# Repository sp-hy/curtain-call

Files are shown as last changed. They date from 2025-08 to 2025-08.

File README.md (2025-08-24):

# CurtainCall - Smart Curtain Controller v2.0

A precision smart curtain controller featuring Zigbee connectivity and magnetic position sensing for accurate, reliable curtain automation.

## Features

- **Precision Position Tracking**: AS5600 magnetic rotation sensor with 0.0879° resolution
- **Zigbee 3.0 Integration**: Full home automation compatibility with window covering cluster
- **Robust Motor Control**: BTS7960 high-current motor driver for smooth, powerful operation
- **Real-time Position Feedback**: Continuous monitoring with 20ms update intervals
- **Advanced Error Handling**: I2C recovery, spike detection, and safety limits
- **Multi-rotation Support**: Handles up to 5 full rotations (1800°) for long curtain runs
- **Auto-calibration**: Intelligent position recovery on power-up

## Bill of Materials (BOM)

### Core Components
| Component | Quantity | Description | Estimated Cost |
|---|---|---|---|
| ESP32 DevKit | 1 | Main microcontroller with Zigbee 3.0 support | $8-12 |
| AS5600 Magnetic Encoder | 1 | 12-bit contactless position sensor | $3-5 |
| BTS7960 Motor Driver | 1 | 43A high-power motor controller | $8-12 |
| 12V DC Geared Motor | 1 | High-torque motor for curtain operation | $15-25 |
| Diametric Magnet | 1 | 6mm diameter for AS5600 sensor | $2-3 |

### Power & Protection
| Component | Quantity | Description | Estimated Cost |
|---|---|---|---|
| 12V 3A Power Supply | 1 | Wall adapter or switching supply | $10-15 |
| LM2596 Buck Converter | 1 | 12V to 5V step-down (optional) | $3-5 |
| Fuse Holder & 5A Fuse | 1 | Motor circuit protection | $2-3 |
| TVS Diode (15V) | 2 | Motor voltage spike protection | $1-2 |

### Mechanical Hardware
| Component | Quantity | Description | Estimated Cost |
|---|---|---|---|
| Motor Mounting Bracket | 1 | Custom or universal motor mount | $5-10 |
| Drive Pulley/Gear | 1 | Connects motor to curtain mechanism | $3-8 |
| Timing Belt/Chain | 1 | Power transmission (if required) | $5-10 |
| Shaft Coupling | 1 | Flexible coupling for sensor mounting | $3-5 |

### Electronics & Wiring
| Component | Quantity | Description | Estimated Cost |
|---|---|---|---|
| Dupont Jumper Wires | 20 | Male-female and male-male connectors | $3-5 |
| Breadboard/PCB | 1 | Prototyping or permanent mounting | $2-8 |
| Terminal Blocks | 4 | Power and motor connections | $2-4 |
| Heat Shrink Tubing | 1 set | Wire protection and insulation | $3-5 |

**Total Estimated Cost: $75-140** (depending on motor choice and sourcing)

## Wiring Diagrams

### Circuit Schematic

```
                     CurtainCall v2.0 Circuit Diagram
    
    12V PSU ───[FUSE]───┬─── BTS7960 VCC ───┬─── M+ ───┐
        │               │                   │          │
        └─── Buck Conv ─┘                   │          │    ┌─── DC MOTOR ───┐
                 │                          │          │    │               │
                5V                          │        [TVS]  │               │
                                            │          │    │               │
    ┌─────────────── ESP32 DevKit ──────────┼──────────┼────┼───────────────┼───┐
    │                                       │          │    │               │   │
    │  GPIO 21 (SDA) ─────────────────────┐ │          │    │               │   │
    │  GPIO 22 (SCL) ─────────────────────┼─┼──────────┼────┼───────────────┼───┼─ GND
    │  GPIO  0 ───── BTS7960 L_EN         │ │          │    │               │   │
    │  GPIO  7 ───── BTS7960 R_EN         │ │          └──M-┘               │   │
    │  GPIO  6 ───── BTS7960 L_PWM        │ │                               │   │
    │  GPIO  5 ───── BTS7960 R_PWM        │ │                               │   │
    │                                     │ │         ┌─── AS5600 ──────────┐   │
    │  3.3V ──────────────────────────────┼─┼─────────┼─ VCC               │   │
    │  GND ───────────────────────────────┼─┼─────────┼─ GND               │   │
    └─────────────────────────────────────┼─┼─────────┼─────────────────────┼───┘
                                          │ │         │                     │
                                          │ └─────────┼─ SDA               │
                                          └───────────┼─ SCL               │
                                                      │                     │
                                              ┌───────┼─ MAGNET ────────────┘
                                              │       └─────────────────────┐
                                              │                             │
                                        Rotating Shaft/Pulley              │
                                              │                             │
                                              └─────── Curtain Rod ─────────┘

    Components:
    - ESP32: Main controller with Zigbee
    - AS5600: Magnetic rotation encoder  
    - BTS7960: High-current motor driver
    - TVS: Transient voltage suppressor
    - Buck Conv: 12V to 5V converter (optional)
```

### Power Distribution

```
12V Power Supply (3A)
│
├── 5A Fuse ──► BTS7960 Motor Driver (12V)
│                    │
│                    └── DC Motor (12V)
│
└── LM2596 Buck Converter (Optional)
         │
         └── 5V for BTS7960 logic (if needed)

ESP32 provides 3.3V for AS5600 sensor
```

### Pin Assignment Table

| ESP32 Pin | Function | Connected To | Signal Type |
|---|---|---|---|
| GPIO 21 | I2C SDA | AS5600 SDA | Digital I2C |
| GPIO 22 | I2C SCL | AS5600 SCL | Digital I2C |
| GPIO 0 | Motor Control | BTS7960 L_EN | Digital Output |
| GPIO 7 | Motor Control | BTS7960 R_EN | Digital Output |
| GPIO 6 | Motor PWM | BTS7960 L_PWM | PWM Output |
| GPIO 5 | Motor PWM | BTS7960 R_PWM | PWM Output |
| 3.3V | Power | AS5600 VCC | Power Supply |
| GND | Ground | All GND pins | Common Ground |

## AS5600 Magnetic Encoder Setup

The AS5600 provides precise angular position measurement with contactless operation:

### Physical Installation
1. **Mount the sensor** securely to a stationary part of the curtain mechanism
2. **Attach the magnet** to the rotating element (motor shaft, pulley, or gear)
3. **Maintain 1-3mm air gap** between magnet and sensor for optimal performance
4. **Center alignment** is critical - magnet must be concentric with sensor
5. **Use diametric magnetization** for best linearity and accuracy

### Technical Specifications
- **I2C Address**: 0x36 (factory default, programmable)
- **Resolution**: 12-bit (4096 steps = 0.0879° per step)
- **Angular Range**: Full 360° rotation
- **Magnetic Field**: 30-100 mT optimal range
- **Update Rate**: 20ms intervals (50Hz) for I2C stability
- **Supply Voltage**: 3.3V from ESP32
- **Current Consumption**: 6.5mA typical

## Software Installation

### Required Libraries
1. **AS5600 Library**: `#include <AS5600.h>`
   - [AS5600 Library](https://github.com/RobTillaart/AS5600) by Rob Tillaart
2. **BTS7960 Motor Driver**: `#include <BTS7960.h>`
   - Available through Arduino Library Manager
3. **Zigbee Core**: Built into ESP32 Arduino Core v3.0+
   - `#include "ZigbeeCore.h"`
   - `#include "ep/ZigbeeWindowCovering.h"`

### Installation Steps
1. **Install ESP32 Arduino Core** (v3.0 or later for Zigbee support)
2. **Install required libraries** through Arduino IDE Library Manager
3. **Upload CurtainCall.ino** to your ESP32
4. **Configure your home automation** to recognize the new Zigbee device

### Configuration Parameters
```cpp
// Hardware configuration (CurtainCall.ino lines 24-38)
const int MOTOR_SPEED = 200;                    // PWM value (0-255)
const float TOTAL_ROTATIONS_0_TO_100 = 5.0;    // Total rotations for full travel
const float MAX_ANGLE_CHANGE_PER_MS = 15.0;    // Spike detection threshold
const unsigned long AS5600_READ_INTERVAL = 20;  // Sensor read interval (ms)
```

## Usage

### Basic Operation
The system tracks curtain position through absolute angle measurement:

- **0%**: Fully closed (0° absolute angle)
- **100%**: Fully open (1800° absolute angle = 5 full rotations)
- **Real-time tracking**: 20ms update intervals with spike detection
- **Multi-rotation support**: Handles up to 5 complete rotations
- **Auto-calibration**: Intelligent position recovery on startup

### Zigbee Integration
The device appears as a **Window Covering** in your Zigbee network with these commands:

| Zigbee Command | Function | Description |
|---|---|---|
| `Open` | `openCurtain()` | Move to 100% open position |
| `Close` | `closeCurtain()` | Move to 0% closed position |
| `GoToLiftPercentage` | `moveToPosition(uint8_t)` | Move to specific percentage |
| `Stop` | `stopCurtain()` | Immediately stop movement |

### System Features
- **Precise Position Control**: 0.0879° resolution with AS5600 encoder
- **Safety Limits**: Automatic stop at 0% and 100% positions  
- **Error Recovery**: I2C communication recovery and spike filtering
- **Smooth Movement**: BTS7960 provides smooth acceleration/deceleration
- **Status Reporting**: Real-time position updates to Zigbee coordinator

### Initial Setup
1. **Power on** the device - it will join your Zigbee network automatically
2. **Manual positioning** - move curtain to known position (e.g., 50% open)
3. **Auto-calibration** - system calculates absolute position based on stored state
4. **Test operation** - use home automation to verify full range movement

## Configuration

### Pin Definitions
```cpp
#define AS5600_SDA 21  // I2C SDA pin
#define AS5600_SCL 22  // I2C SCL pin
#define MOTOR_L_EN 0   // Motor enable left
#define MOTOR_R_EN 7   // Motor enable right
#define MOTOR_L_PWM 6  // Motor PWM left
#define MOTOR_R_PWM 5  // Motor PWM right
```

### Motor Settings
```cpp
const int MOTOR_SPEED = 200;        // PWM value (0-255)
const int UPDATE_INTERVAL_MS = 100; // Position update frequency
```

## Troubleshooting

### Power Issues
- **Device not starting**: Check 12V power supply capacity (minimum 2A)
- **Random resets**: Verify all ground connections are secure
- **Motor stops unexpectedly**: Check fuse, may need higher current rating

### AS5600 Sensor Issues
- **Position not updating**: Check I2C wiring (SDA/SCL crossed or loose)
- **Erratic readings**: Verify magnet alignment (must be centered over sensor)
- **Sensor timeouts**: System includes automatic I2C recovery after 5 failures
- **Wrong direction**: Adjust `MOTOR_DIRECTION_INVERTED` in code

### Motor Control Issues  
- **Motor not responding**: Verify BTS7960 enable pins and PWM connections
- **Wrong rotation direction**: Check motor wires or toggle direction setting
- **Jerky movement**: Reduce `MOTOR_SPEED` value or check mechanical binding
- **Overshooting target**: Adjust `DEGREES_PER_PERCENT` for your curtain travel

### Zigbee Connectivity
- **Device not joining network**: Ensure ESP32 Arduino Core v3.0+ is installed
- **Commands not working**: Check if device appears as "Window Covering" type
- **Position not updating**: Verify Zigbee coordinator supports position feedback

### Position Tracking
- **Incorrect position after power-up**: System auto-calibrates based on last known position
- **Drift over time**: Check for mechanical backlash in drive system
- **Sudden position jumps**: Spike detection active - check magnet mounting
- **Limited range**: Adjust `TOTAL_ROTATIONS_0_TO_100` for your curtain system

## Advanced Features

### Custom Rotation Range
Modify the rotation range for different curtain mechanisms:

```cpp
curtain.totalRotation = 180.0; // For 180-degree rotation
```

### Direction Configuration
Change sensor direction if needed:

```cpp
as5600.setDirection(AS5600_COUNTERCLOCK_WISE);
```

### Error Handling
The system includes error checking for:
- Sensor communication failures
- Invalid position values
- Motor control issues

## License

This project is open source. Please refer to the individual library licenses for the AS5600 and other dependencies.

## Contributing

Contributions are welcome! Please feel free to submit pull requests or open issues for bugs and feature requests.

## Acknowledgments

- [Rob Tillaart](https://github.com/RobTillaart) for the excellent AS5600 library
- The open source community for Zigbee and motor control libraries

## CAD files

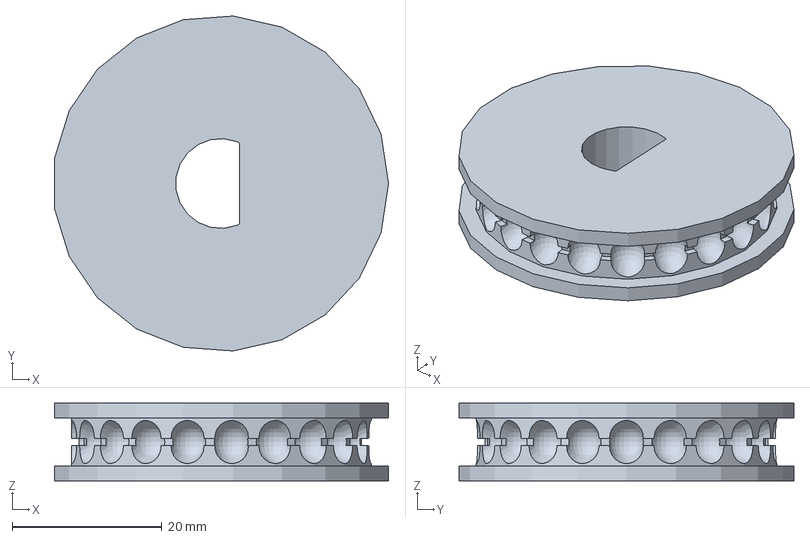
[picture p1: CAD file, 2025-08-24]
3D parts/gear/bead_chain_gear-12mm.3mf
44.6 x 44.7 x 10.4 mm

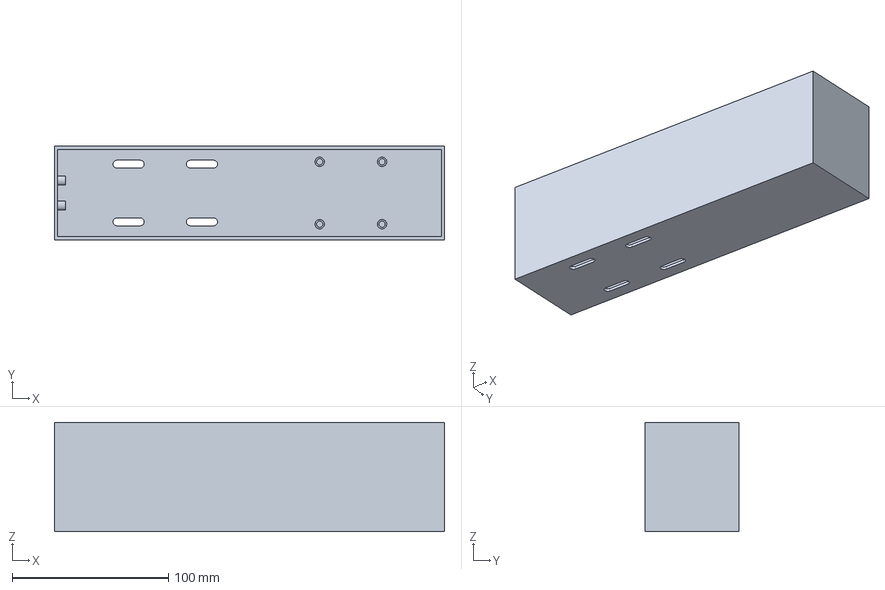
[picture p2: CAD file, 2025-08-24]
3D parts/housing/housing.FCStd
250.0 x 60.0 x 70.0 mm

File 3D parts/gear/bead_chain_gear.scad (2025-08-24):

$fn=21;
r = 20.1275367222;
ball_radius = 4.6/2; //6.05/2; //4.45/2;
h = ball_radius * 2 * (1 + .25 + .2 );
echo(h);
n_teeth=21;
link_radius=.5;
cover_height=2;
shaft_radius = 12/2; // 12mm diameter D-shaft
d_shaft_flat_depth = 0.5; // Adjust this value to match your motor shaft's flat depth

module make_sphere_ring(ring_radius, sphere_radius, num_spheres) {
  union(){
    for (i = [0:num_spheres]){
      rotate([0,0,i*360/num_spheres])
        translate([ring_radius,0,0])hull() {
          sphere(sphere_radius);
          translate([-.5 * sphere_radius,0,0])sphere(sphere_radius);
          translate([0,0,.25 * sphere_radius])sphere(sphere_radius);
          translate([0,0,-.25 * sphere_radius])sphere(sphere_radius);
        }
    }
  }
}

module make_torus(ring_radius, inner_radius) {
  // openscad apparently can't handle rotate_extrude in a difference, so this isn't a real cylinder
  /*rotate_extrude(convexity=10)translate([ring_radius, 0, 0])circle(inner_radius);*/
  difference() {
    cylinder (
        h = inner_radius*2,
        r = ring_radius,
        center = true);
    cylinder (
        h = inner_radius * 2,
        r = ring_radius - 2*inner_radius,
        center = true);
  }
}

module bead_ring() {
  union() {
    make_sphere_ring(r, ball_radius, n_teeth);
    make_torus(r, link_radius);
  }
}

module d_shaft_hole(shaft_r, flat_depth, shaft_height) {
  difference() {
    cylinder(r=shaft_r, h=shaft_height, center=true);
    translate([shaft_r - flat_depth, 0, 0])
      cube([shaft_r, shaft_r * 2, shaft_height + 1], center=true);
  }
}

module make_gear() {
  difference() {
    union() {
      cylinder(h=h, r=r, center=true);
      translate([0,0,-.9*(h-cover_height)])
        cylinder(h=cover_height, r=r+ball_radius, center=true);
      translate([0,0,.9*(h-cover_height)])
        cylinder(h=cover_height, r=r+ball_radius, center=true);
    }
    /*cylinder(h=h, r=r, center=true);*/
    # d_shaft_hole(shaft_radius, d_shaft_flat_depth, h + 4 * cover_height);
    # bead_ring();
  }
}

make_gear();
/*bead_ring() ;*/
/*make_torus(r, link_radius);*/

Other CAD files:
3D parts/housing/housing.3mf

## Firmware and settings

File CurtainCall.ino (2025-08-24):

/*
 * CurtainCall - Smart Curtain Controller
 * 
 * Motorized curtain control system with Zigbee connectivity
 * Features precision position tracking using AS5600 magnetic encoder
 * 
 * Hardware:
 * - ESP32 microcontroller
 * - BTS7960 motor driver
 * - AS5600 magnetic rotary encoder
 * - DC motor with magnetic coupling
 * 
 * Author: CurtainCall Project
 * Version: 2.0
 */

#include <BTS7960.h>
#include "ZigbeeCore.h"
#include "ep/ZigbeeWindowCovering.h"
#include <AS5600.h>
#include <Wire.h>

// Hardware pin assignments
#define ZIGBEE_ENDPOINT 10
#define MOTOR_L_EN 0
#define MOTOR_R_EN 7
#define MOTOR_L_PWM 6
#define MOTOR_R_PWM 5
#define SDA_PIN 21
#define SCL_PIN 22

// System configuration
const int MOTOR_SPEED = 200;
const bool MOTOR_DIRECTION_INVERTED = true;
const unsigned long AS5600_READ_INTERVAL = 20;  // 20ms for I2C stability
const float TOTAL_ROTATIONS_0_TO_100 = 5.0;    // Configure for your curtain travel
const float DEGREES_PER_PERCENT = TOTAL_ROTATIONS_0_TO_100 * 360.0 / 100.0;
const float MAX_ANGLE_CHANGE_PER_MS = 15.0;    // Spike detection threshold

// Hardware interfaces
BTS7960 motor(MOTOR_L_EN, MOTOR_R_EN, MOTOR_L_PWM, MOTOR_R_PWM);
AS5600 as5600;
ZigbeeWindowCovering zigbeeEndpoint(ZIGBEE_ENDPOINT);

// System state
struct {
  uint8_t current = 100;      // Current position (0-100%)
  uint8_t target = 100;       // Target position (0-100%)
  bool isMoving = false;      // Movement state
  int direction = 0;          // 1=opening, -1=closing, 0=stopped
  float absoluteAngle = 0.0;  // Absolute angle from 0% position
  bool calibrated = false;    // Calibration status
} curtain;

// Encoder state
struct {
  float lastAngle = 0.0;
  float currentAngle = 0.0;
  float validAngle = 0.0;     // Last validated reading
  int rotationCount = 0;      // Track multiple rotations
  bool initialized = false;
  unsigned long lastReadTime = 0;
} encoder;

void setup() {
  // Initialize hardware
  initializeMotor();
  initializeEncoder();
  initializeZigbee();
  
  // Set initial position
  zigbeeEndpoint.setLiftPercentage(curtain.current);
}

void loop() {
  // Update encoder reading
  if (millis() - encoder.lastReadTime >= AS5600_READ_INTERVAL) {
    updateEncoder();
  }
  
  // Update position and motor control
  updatePosition();
}

void initializeMotor() {
  motor.begin();
  motor.enable();
  motor.stop();
}

void initializeEncoder() {
  // Configure I2C for reliability
  Wire.begin(SDA_PIN, SCL_PIN);
  Wire.setClock(100000);  // 100kHz for stability
  Wire.setTimeout(1000);
  
  // Initialize AS5600
  as5600.begin();
  
  if (!as5600.isConnected()) {
    return;  // Continue without encoder if not available
  }
  
  // Read initial position
  uint16_t rawAngle = as5600.readAngle();
  encoder.currentAngle = rawAngle * AS5600_RAW_TO_DEGREES;
  encoder.lastAngle = encoder.currentAngle;
  encoder.validAngle = encoder.currentAngle;
  encoder.rotationCount = 0;
  encoder.initialized = true;
  
  // Auto-calibrate based on stored position
  float targetAbsoluteAngle = curtain.current * DEGREES_PER_PERCENT;
  encoder.rotationCount = round((targetAbsoluteAngle - encoder.currentAngle) / 360.0);
  curtain.absoluteAngle = encoder.rotationCount * 360.0 + encoder.validAngle;
  curtain.calibrated = true;
}

void initializeZigbee() {
  // Configure device properties
  zigbeeEndpoint.setManufacturerAndModel("LC", "CurtainCall2");
  zigbeeEndpoint.setCoveringType(DRAPERY);
  zigbeeEndpoint.setConfigStatus(true, true, false, true, true, true, true);
  zigbeeEndpoint.setMode(false, true, false, false);
  zigbeeEndpoint.setLimits(0, 200, 0, 0);
  
  // Register command callbacks
  zigbeeEndpoint.onOpen(openCurtain);
  zigbeeEndpoint.onClose(closeCurtain);
  zigbeeEndpoint.onGoToLiftPercentage(moveToPosition);
  zigbeeEndpoint.onStop(stopCurtain);
  
  Zigbee.addEndpoint(&zigbeeEndpoint);
  
  // Connect to network
  if (!Zigbee.begin()) {
    ESP.restart();  // Restart if Zigbee fails
  }
  
  while (!Zigbee.connected()) {
    delay(100);
  }
}

void updateEncoder() {
  if (!as5600.isConnected() || !encoder.initialized) {
    return;
  }
  
  // Read with retry logic for reliability
  uint16_t rawAngle = 0;
  bool readSuccess = false;
  
  for (int attempt = 0; attempt < 3 && !readSuccess; attempt++) {
    if (attempt > 0) delay(5);
    
    unsigned long startTime = micros();
    if (as5600.isConnected()) {
      rawAngle = as5600.readAngle();
      if ((micros() - startTime) < 20000) {  // Valid if < 20ms
        readSuccess = true;
      }
    }
  }
  
  // Handle failed reads gracefully
  if (!readSuccess) {
    static unsigned long consecutiveErrors = 0;
    consecutiveErrors++;
    
    // Attempt I2C recovery after multiple failures
    if (consecutiveErrors >= 5) {
      Wire.end();
      delay(50);
      Wire.begin(SDA_PIN, SCL_PIN);
      Wire.setClock(100000);
      Wire.setTimeout(1000);
      delay(50);
      consecutiveErrors = 0;
    }
    
    encoder.currentAngle = encoder.validAngle;
    encoder.lastReadTime = millis();
    return;
  }
  
  encoder.currentAngle = rawAngle * AS5600_RAW_TO_DEGREES;
  
  // Spike detection and filtering
  unsigned long currentTime = millis();
  unsigned long deltaTime = max(1UL, currentTime - encoder.lastReadTime);
  
  float angleDifference = encoder.currentAngle - encoder.lastAngle;
  
  // Handle 360° rollover
  if (angleDifference > 180.0) angleDifference -= 360.0;
  else if (angleDifference < -180.0) angleDifference += 360.0;
  
  // Check for unreasonable changes (spikes)
  float maxChange = MAX_ANGLE_CHANGE_PER_MS * deltaTime;
  if (curtain.isMoving) maxChange *= 2.0;  // More lenient when moving
  
  bool isValidReading = (encoder.lastReadTime == 0) || 
                       (abs(angleDifference) <= maxChange) || 
                       (abs(angleDifference) >= 300.0);  // Allow rollovers
  
  if (isValidReading) {
    encoder.validAngle = encoder.currentAngle;
  } else {
    encoder.currentAngle = encoder.validAngle;  // Use last valid reading
  }
  
  // Track rotation count for absolute positioning
  float validAngleDiff = encoder.validAngle - encoder.lastAngle;
  if (validAngleDiff > 180.0) encoder.rotationCount--;
  else if (validAngleDiff < -180.0) encoder.rotationCount++;
  
  // Calculate absolute position
  float rawAbsoluteAngle = encoder.rotationCount * 360.0 + encoder.validAngle;
  curtain.absoluteAngle = constrain(rawAbsoluteAngle, 0.0, 1800.0);
  
  encoder.lastAngle = encoder.validAngle;
  encoder.lastReadTime = currentTime;
}

void updatePosition() {
  if (!curtain.isMoving || !curtain.calibrated) return;
  
  // Calculate current position percentage
  float currentPercent = curtain.absoluteAngle / DEGREES_PER_PERCENT;
  currentPercent = constrain(currentPercent, 0.0, 100.0);
  uint8_t newPosition = (uint8_t)round(currentPercent);
  
  // Update Zigbee when position changes
  if (newPosition != curtain.current) {
    curtain.current = newPosition;
    zigbeeEndpoint.setLiftPercentage(curtain.current);
  }
  
  // Check if target reached
  float targetAngle = curtain.target * DEGREES_PER_PERCENT;
  if (abs(curtain.absoluteAngle - targetAngle) <= DEGREES_PER_PERCENT) {
    stopMotor();
    curtain.current = curtain.target;
    zigbeeEndpoint.setLiftPercentage(curtain.current);
    return;
  }
  
  // Safety limits
  if ((curtain.absoluteAngle <= 0.0 && curtain.direction < 0) ||
      (curtain.absoluteAngle >= 1800.0 && curtain.direction > 0)) {
    stopMotor();
    curtain.current = constrain(round(curtain.absoluteAngle / DEGREES_PER_PERCENT), 0, 100);
    curtain.target = curtain.current;
    zigbeeEndpoint.setLiftPercentage(curtain.current);
  }
}

void startMotor(int direction) {
  motor.pwm = MOTOR_SPEED;
  
  int motorDirection = MOTOR_DIRECTION_INVERTED ? -direction : direction;
  
  if (motorDirection > 0) motor.front();
  else if (motorDirection < 0) motor.back();
  
  curtain.isMoving = true;
  curtain.direction = direction;
}

void stopMotor() {
  motor.stop();
  curtain.isMoving = false;
  curtain.direction = 0;
}

void moveToPosition(uint8_t targetPercent) {
  if (!curtain.calibrated) return;
  
  stopMotor();
  curtain.target = constrain(targetPercent, 0, 100);
  
  if (abs(curtain.target - curtain.current) <= 1) return;  // Already there
  
  float targetAngle = curtain.target * DEGREES_PER_PERCENT;
  int direction = (targetAngle > curtain.absoluteAngle) ? 1 : -1;
  
  startMotor(direction);
}

// Zigbee command callbacks
void openCurtain() {
  moveToPosition(100);
}

void closeCurtain() {
  moveToPosition(0);
}

void stopCurtain() {
  stopMotor();
  zigbeeEndpoint.setLiftPercentage(curtain.current);
}

void calibratePosition(uint8_t knownPosition) {
  if (!encoder.initialized) return;
  
  stopMotor();
  encoder.rotationCount = 0;
  curtain.absoluteAngle = encoder.validAngle;
  curtain.current = constrain(knownPosition, 0, 100);
  curtain.target = curtain.current;
  curtain.calibrated = true;
}

void emergencyStop() {
  stopMotor();
  encoder.rotationCount = 0;
  curtain.absoluteAngle = curtain.current * DEGREES_PER_PERCENT;
}
